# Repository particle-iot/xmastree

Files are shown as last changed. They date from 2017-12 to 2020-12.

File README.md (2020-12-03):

# PARTICLE CHRISTMAS TREE

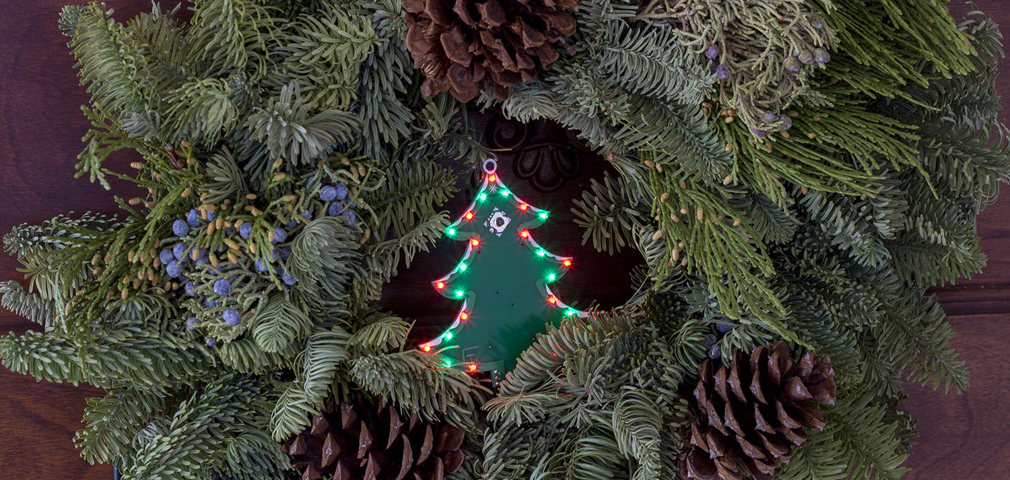
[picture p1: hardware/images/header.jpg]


It's a Happy Hardware Holiday for all! Meet the Particle Christmas Tree, a limited edition PCB packed full of cheer with customizable light patterns and holiday tunes. Use your tree with a Particle Photon or Electron to light up the LEDs and play music. Control your tree from the onboard joystick or from the Christmas Tree Web App.

Learn how to get started below. Happy Holidays from Team Particle!

## THINGS YOU'LL NEED
 - Christmas Tree
 - Micro USB cable
 - USB power supply (2A minimum rating)
 - Your Photon or Electron (new to Particle? Get started [here](https://docs.particle.io/guide/getting-started).)
 - Eggnog (optional)

## STEPS 

You can setup the tree in a matter of minutes.

1. Insert the Photon into the socket
1. Plug in the USB power supply
1. Flash [the Christmas tree firmware from the Web IDE][Firmware shared app] - no downloads required.
1. [Open the web interface][Web interface] and spread the cheer!

[Firmware shared app]: https://go.particle.io/shared_apps/5fc8c888e6f0b000092cf113
[Web interface]: https://particle-iot.github.io/xmastree

<p align="center">
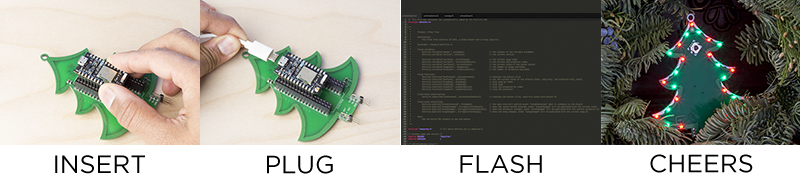
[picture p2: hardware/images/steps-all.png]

</p>

## GET TO KNOW YOUR TREE

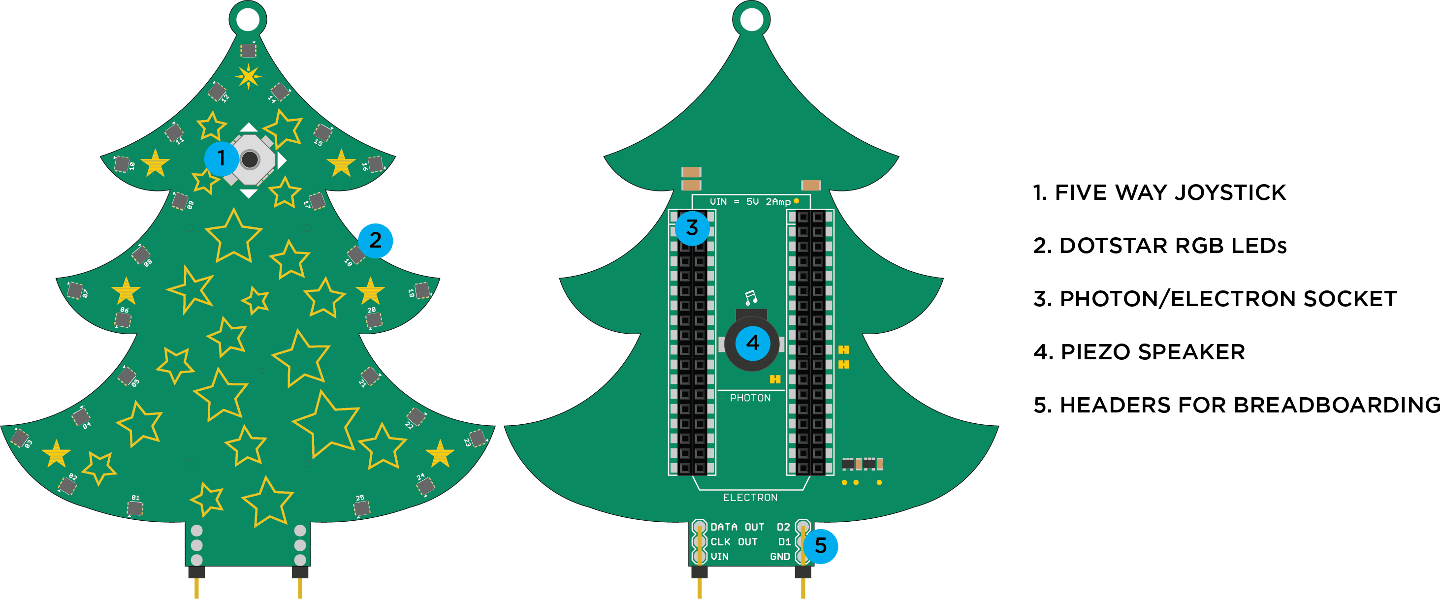
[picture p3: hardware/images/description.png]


### Joystick

The joystick is a 5 way button: up, down, left, right, and center (push in) then you can reprogram the usage any way you'd like. We have setup the button for you in the Christmas tree firmware to toggle light patterns and music.

|DIR | PIN |
|:---  |:--- |
|UP |D4| 
|DOWN  |A0|
|LEFT  |D5|
|RIGHT |D3|
|CENTER|D6|

### Dotstar RGB LEDs

The tree has 25 of the [APA102](http://www.led-color.com/upload/201604/APA102-2020%20SMD%20LED.pdf) 2020 RGB LEDs (also commonly known as dotstars) connected in a daisy chain. These LEDs are individually addressable using two pins, data and clock. These tiny stars are incredibly bright and fast. At full brightness, with all colors turned ON, each LED will consume about 60mA of current. So 25 of them will consume a max of 1.5Amp. This is why we recommend powering the tree with a **5VDC power supply that can source at least 2Amp.** Most modern USB phone chargers should be able to meet this demand.

### Photon/Electron Socket

The two dual-row headers allow you to use either the Particle Photon or the Electron. Please take care of the orientation and position of the device while plugging in.

### Piezo speaker

At the back of the tree you'll find a piezo speaker connected to pin D0. The firmware includes several 8-bit holiday tunes but you can also compose your own. This speaker can be a bit loud. If you'd like to reduce the volume, you can put a piece of tape on its opening.

### Headers for breadboarding

These pins breakout the power and control signal of the tree. You can mount the tree on a breadboard with the help of these pins. This will allow you to connect different hardware to your tree, daisy chain multiple trees, add more LEDs or even control it with other microcontrollers.

|PIN |DESCRIPTION|
|:---|:---|
|D1 | Connected to the D1 pin of the Particle device and acts as CLOCK IN to the LEDs.|
|D2 | Connected to the D2 pin of the Particle device and acts as DATA IN to the LEDs.|
|DATA OUT| DATA OUT pin of the LEDs.|
|CLK OUT | CLOCK OUT pin of the LEDs.|
|VIN | Input power to the tree and Particle device. This pin is connected to the VIN pin of the Particle device. 5VDC max .|
|GND | Connected to the ground.|

## SETTING UP THE TREE 

You can either use a Particle Photon or an Electron to control the tree. Since the dotstar RGB LEDs work at 5VDC, you'll need to make sure that the USB cable is plugged in at all times to power the tree, unless you have powered the tree via a separate power source via the VIN pin.

> **NOTE:** When controlled by an Electron, the tree will not work with just the LiPo battery plugged in. You'll need to connect the USB cable as well or other external 5V DC power source.

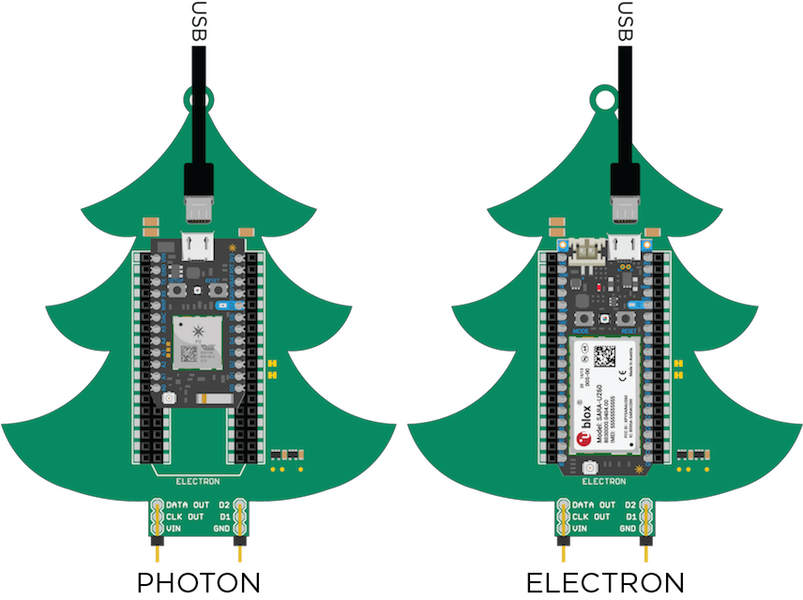
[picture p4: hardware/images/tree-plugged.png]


## WAYS TO SET UP THE TREE

### As an ornament

The easiest way to setup the tree is to hang it as an ornament while powering over USB. You can also rig up your own 5V power supply cable and plug it into the header.

### On a breadboard

You can use the bottom header to mount the tree on a breadboard and power/control it via your own choice of hardware or to daisy chain the tree to other trees or dotstar projects.

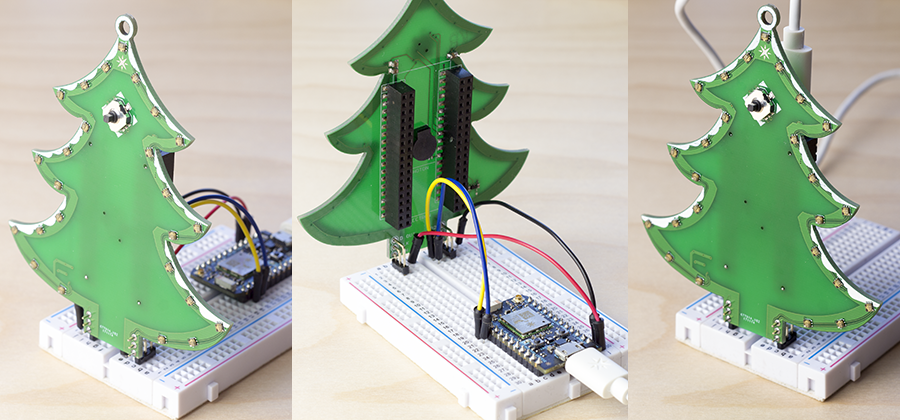
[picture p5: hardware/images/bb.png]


## USING THE WEB INTERFACE

<p align="center">
<a href="https://particle-iot.github.io/xmastree" target="_blank">
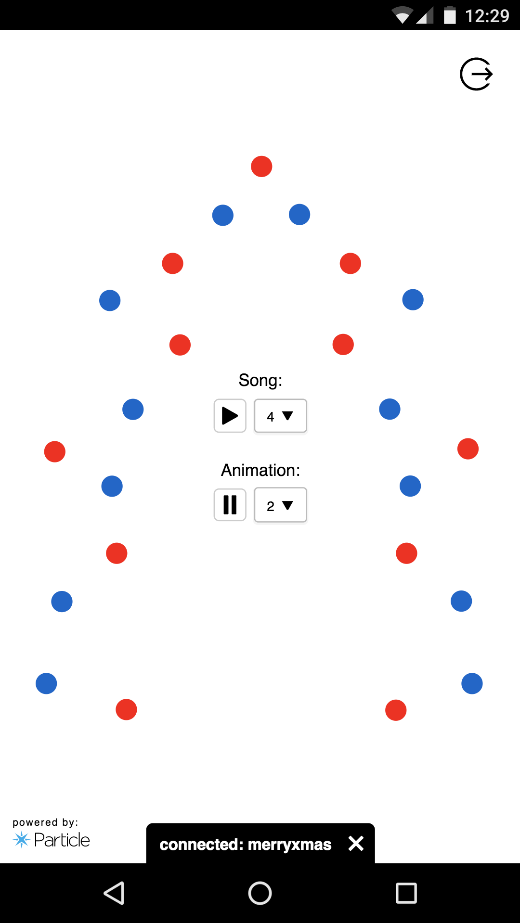
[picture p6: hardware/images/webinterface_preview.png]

</a></p>

There is [a hosted version of the web interface you can use to control your tree][Web interface]. Simply login with your Particle account, select your device and you'll be able to control the LEDs and music from a desktop or mobile browser.

## MODIFYING THE FIRMWARE

[][Firmware shared app]

Import the firmware to your Particle account in the Web IDE with the button above. You'll be
able to add new songs or tweak the functionality to your heart's
content.

Click [here](FIRMWARE.md) for more information about the Xmas Tree firmware.

## CONNECT

Having problems or have awesome suggestions? Connect with us on our [forum](https://community.particle.io/).

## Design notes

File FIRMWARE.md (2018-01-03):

# Particle Christmas Tree Firmware

## Introduction

The firmware of the Xmas Tree circuit board is based on Wiring to be run on Particle devices like the Photon and the Electron (or other compatible device like RedBear Duo) with cloud connectivity. For the details and installation, please refer to the Xmas Tree [user manual](/README.md). It controls the main components of the tree includes the 25 LEDs, the 5-way joystick and the piezo speaker. It detects the 5-way joystick buttons for user inputs to select LED animations and Xmas songs to play.

With the firmware, you will be able to learn how to use the Photon and the Electron connected to the cloud and demostrates how to:

* define cloud functions for controlling the tree over the Particle cloud
* generate tones using the piezo buzzer
* create beautiful animation effects using the LEDs
* control the tree state using the 5-way joystick

Feel free to hack, modify or inspire any new features in the firmware source code and remember to share with everyone for your great work. An example of new feature is to add an ultrasonic sensor to the tree for motion detection and then the tree starts to play a paricular song or LED animation.

## How It Works

The firmware keeps track of user inputs by monitoring the 5-way joystick button and performs the following tasks:

|BUTTON|TASKS|
|:---  |:--- |
|UP |Play Previous Animation| 
|DOWN  |Play Next Animation|
|LEFT  |Play Previous Song|
|RIGHT |Play Next Song|
|CENTER|Toggle Tree State|

The CENTER button controls the tree with four states by toggling the following sequence:

*	(S) --> Play Both Song and Animation --> Stop Both --> Play Animation Only --> Play Song Only --> (S) 

## Source Files

### xmastree.ino

The firmware starts from the [xmastree.ino](/src/firmware/xmastree.ino) and it calls the `setup()` function at once for setting up and initialize the hardware components:

* `ledsInit()`, LEDs by using the dotstar library
* `joystickPortInit()`, 5-way joystick button with interrupt enabled
* `buzzerPortInit()`, piezo speaker

It also exposes the tree cloud functions and variables, subscribes to the tree cloud events as well:

* `cloudInit()`

After that, it will create two threads (as workers) for processing the pre-defined songs and animations:

* `animationWorker`
* `songWorker`
  
Finally, it runs the `loop()` function repeatedly to keep track of buttons and cloud events.

It calls `processButtons()` for user inputs and by adding/subtracting the variables `currentState`, `currentSong` and `currentAnimation` so that the threads can handle how to play the songs and animations. Also, it calls `processCloud()` for any events coming from the cloud over the Internet and controlling the variables as well.

Note: You can set the brightness of the LEDs to higher but less than 80 is highly recommanded for safety (too hot) and your eyes (too bright).
 
* `#define LED_BRIGHTNESS      30` 

### xmastree.h

The [xmastree.h](/src/firmware/xmastree.h) header file defines the hardware pins of the components such as the piezo speaking and the 5-way joystick. It also defines some macros for using in the source code. Normally, you do not need to modify this file.  

### songs.h

The [songs.h](/src/firmware/songs.h) file contains some pre-defined Xmas songs to be gernerated by the piezo speaker. You can modify it by adding your favorite songs there.

### animations.h

The [animations.h](/src/firmware/animations.h) file contains some pre-defined LED animations to be gernerated by the 25 LEDs. You can modify it by adding your own LED animations there.

### Cloud Variables/Functions/Events

The cloud items are exposed for the [Web App](https://particle-iot.github.io/xmastree) to control the tree over the Internet so that you can control the tree remotely.

#### Variables

|NAME |DESCRIPTION |
|:--- |:--- |
|whoami |Variable `projName`, the current project name `xmastree` will be sent out by default|
|version  |Variable `version`, the current firmware version |
|currSong |Variable `currentSong`, the current song index |
|currAnim |Variable `currentAnimation`, the current LED animation index |
|currState|Variable `currentState`, the current state of the tree |
|songCount|Variable `songCount`, the number of songs available |
|animCount|Variable `animationCount`, the number of animations available |

#### Functions
 
|NAME |DESCRIPTION |
|:--- |:--- |
|setState |`setState()`, set the current state of the tree state (none, song only, led animation only, both)|
|playSong |`playSong(String index)`, play song by index|
|stopSong |`stopSong()`, stop song|
|playAnim |`playAnimation(String index)`, play LED animation by index|
|stopAnim |`stopAnimation()`, stop LED animation|

#### Events (Publishing)

|NAME |DESCRIPTION |
|:--- |:--- |
|xtreeConnected |Variable `ProjName`, the xmas tree will publish event "xtreeConnected" with the variable once it connects to the clould |
|stateChanged |Variable `currentState`, when the center button pressed, event "stateChanged" will be published with the current state|
|animChanged |Variable `currentAnimation`, when the animation changed, event "animChanged" will be published with the current animation ID|
|songChanged |Variable `currentSong`, when the song changed, event "songChanged" will be published with the current song ID|

You can add your own events to the firmware and use the [console](https://console.particle.io/events) to monitor the cloud events for testing.

## Credits

* [midiToArduino](https://www.extramaster.net/tools/midiToArduino/)

## References

* [Main Page](https://github.com/particle-iot/xmastree)
* [User Manual](/README.md)
* [Web App](https://particle-iot.github.io/xmastree)

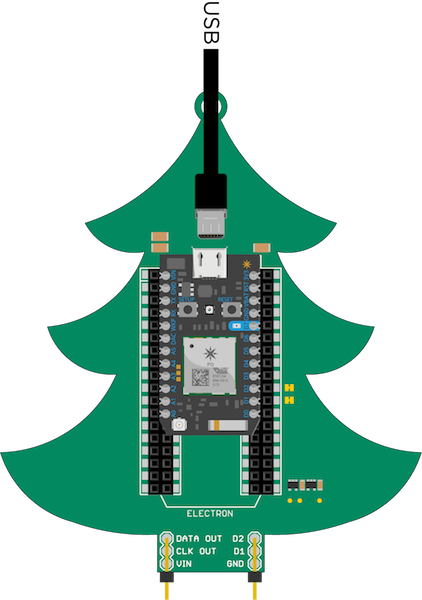
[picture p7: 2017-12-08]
hardware/images/tree-photon.png

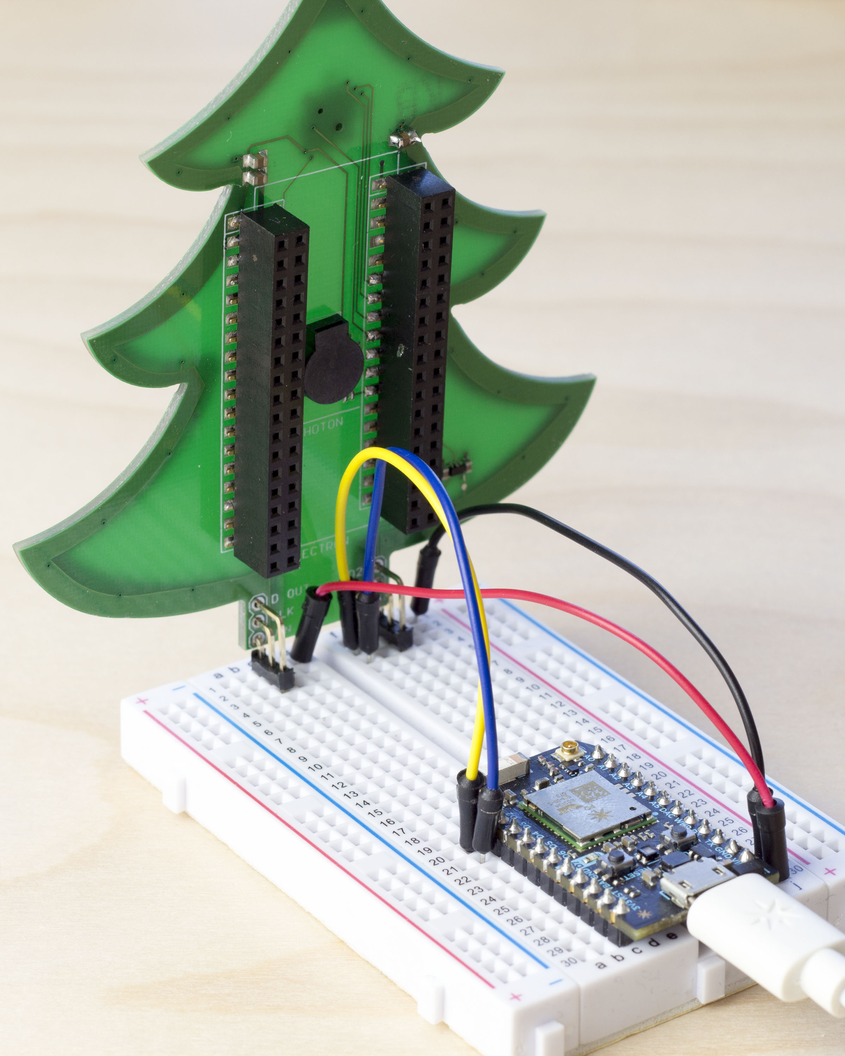
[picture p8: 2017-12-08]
hardware/images/bb03.jpg

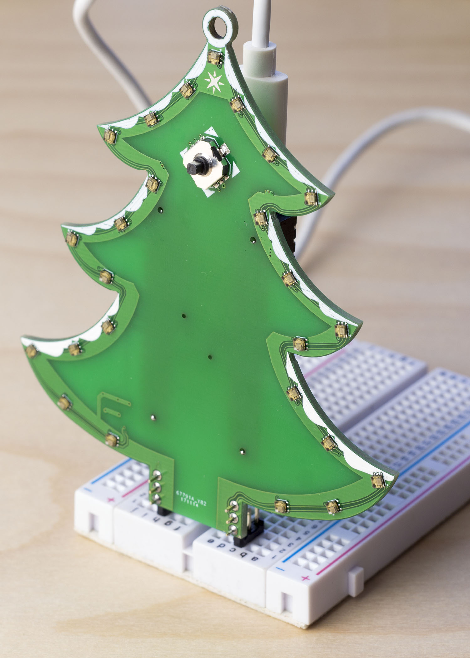
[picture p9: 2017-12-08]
hardware/images/bb01.jpg

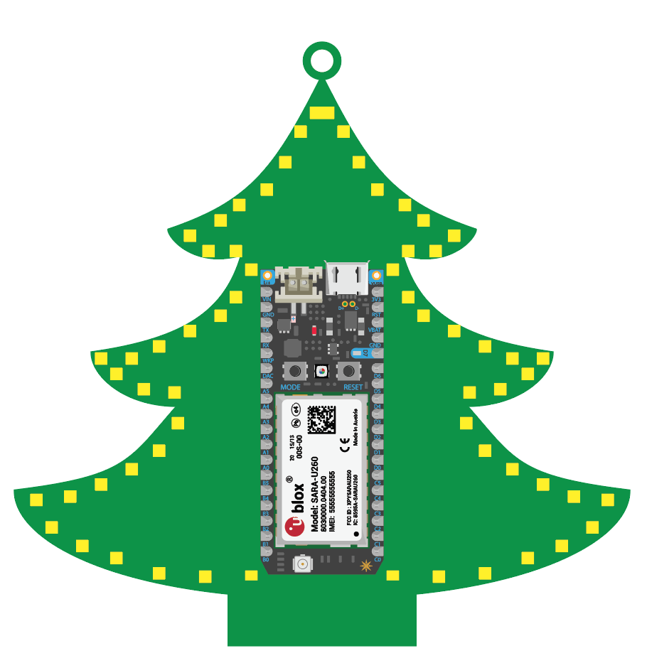
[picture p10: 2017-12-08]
hardware/images/shape-mockup.jpg

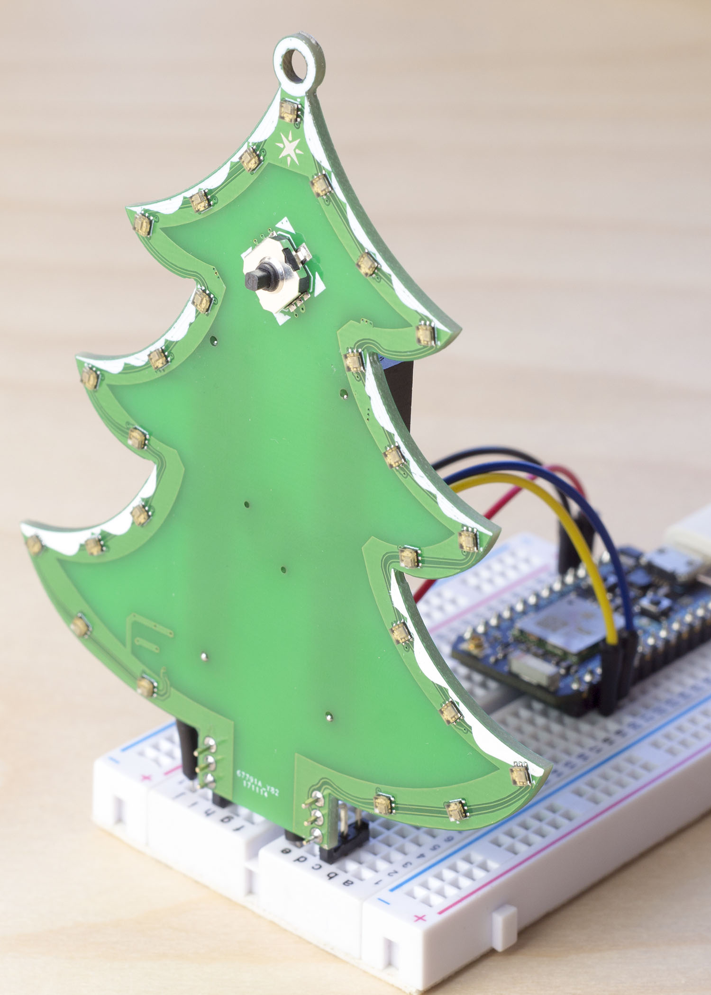
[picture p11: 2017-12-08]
hardware/images/bb02.jpg

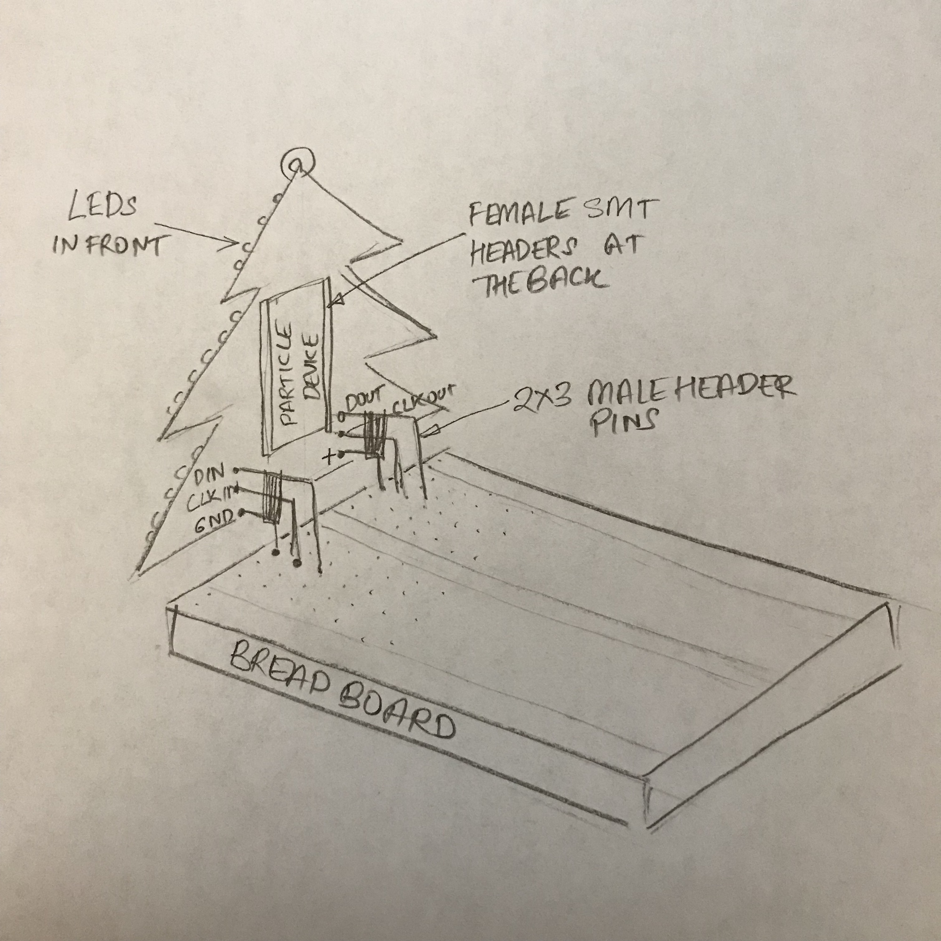
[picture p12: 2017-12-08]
hardware/images/header-location.jpg

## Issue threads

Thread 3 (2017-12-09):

Set RGB ordering

beriberikix, 2017-12-09:
In order to get the correct color when calling `setPixelColor()`, I had to change the initialization to:
`Adafruit_DotStar leds = Adafruit_DotStar(TOTAL_LED, PIN_LED_DATA, PIN_LED_CLOCK, DOTSTAR_BGR);`

@Cheong2K are you able to confirm if that's needed?

Cheong2K, 2017-12-16:
Thanks @beriberikix and @monkbroc for fixing this, nice!!

Closed 2017-12-15.

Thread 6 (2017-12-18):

Twinkle

Mohoganogan, 2017-12-18:
How about one that is all green and then a single random led twinkles white then goes back to green to provide an old school simple look.

beriberikix, 2017-12-18:
Great idea @Mohoganogan! We can see if someone has a extra time but pull requests are always welcome!

Mohoganogan, 2017-12-30:
I ended up using this code for my tree:
[https://github.com/WTFox/xmas-tree](https://github.com/WTFox/xmas-tree)

Modified to use only one of the patterns.

`// This #include statement was automatically added by the Particle IDE.
// https://github.com/WTFox/xmas-tree
#include <FastLED.h>

#include "FastLED/FastLED.h"
FASTLED_USING_NAMESPACE;

#if FASTLED_VERSION < 3001000
#error "Requires FastLED 3.1 or later; check github for latest code."
#endif

#define DATA_PIN D2
#define CLOCK_PIN D1
#define LED_TYPE WS2811
#define COLOR_ORDER GRB
#define NUM_LEDS 25
CRGB leds[NUM_LEDS];

#define BRIGHTNESS 5
#define FRAMES_PER_SECOND 12
#define MAX_ARGS 64

#define ARRAY_SIZE(A) (sizeof(A) / sizeof((A)[0]))

int lightsOn(String input);
int lightsOff(String input);
int toggleLights(String args);
int setBright(String brightness);
int twitterMention(String args);
void addGlitter(NSFastLED::fract8 chanceOfGlitter);

// list of patterns to cycle through.  each is defined as a separate function
// below.
typedef void (*SimplePatternList[])();
SimplePatternList gPatterns = {confetti};
//SimplePatternList gPatterns = {rainbow, rainbowWithGlitter, confetti, sinelon, juggle, bpm};

uint8_t gCurrentPatternNumber = 0;  // Index number of which pattern is current
uint8_t gHue = 0;  // rotating "base color" used by many of the patterns

void setup() {
  // Publishing particle functions and vars.
  FastLED.addLeds<APA102, DATA_PIN, CLOCK_PIN>(leds, NUM_LEDS);
  Particle.function("lightsOn", lightsOn);
  Particle.function("lightsOff", lightsOff);
  Particle.function("toggleLights", toggleLights);
  Particle.function("brightness", setBright);
  Particle.function("tweet", tweet);
  Particle.function("twitMention", twitterMention);
  delay(3000);  // 3 second delay for recovery

//  FastLED.addLeds<LED_TYPE, DATA_PIN, COLOR_ORDER>(leds, NUM_LEDS).setCorrection(TypicalLEDStrip);

  // set master brightness control
  FastLED.setBrightness(BRIGHTNESS);
}

bool mentioned = false;
bool lightState = true;
bool currentState = true;
int lightBrightness = 100;

String onMessages[] = {"Lighting it up for Christmas!",
                       "Let's get LIT!",
                       "HO HO HO!, It's Christmas Time!",
                       "Christmas Tree, OH Christmas ME!",
                       "My lights are brightly shining!"};

String offMessages[] = {"No more xmas.. FOR NOW!?",
                        "I'm going to sleep. ZZzz...ZZzzz..",
                        "O-Holy-Night!",
                        "Going away. I'll be home for Christmas"};

void loop() {
  // main loop
  if (currentState != lightState) {
    lightState = currentState;
  }

  if (lightState == true) {
    // Call the current pattern function once, updating the 'leds' array
    gPatterns[gCurrentPatternNumber]();

    // send the 'leds' array out to the actual LED strip
    FastLED.show();
    // insert a delay to keep the framerate modest
    FastLED.delay(1000 / FRAMES_PER_SECOND);

    // do some periodic updates
    // slowly cycle the "base color" through the rainbow
    EVERY_N_MILLISECONDS(20) {
        gHue++;
        if (mentioned) {
            // Blink the tree lights 5 times if mentioned on twitter
            for (int i=0; i<5; i++) {
                FastLED.clear();
                FastLED.show();
                delay(250);
                rainbow();
                FastLED.show();
                delay(250);
            }
            mentioned = false;
        }
    }

    // change patterns periodically
    EVERY_N_SECONDS(10) {
        nextPattern();
    }
  }
}

// Particle functions.
// Per the docs, hese functions HAVE to return an int
// and accept a String as a parameter.
int tweet(String msg) {
    Particle.publish("sendTweet", msg, 60, PRIVATE);
    return 0;
}

int setBright(String brightness) {
  lightBrightness = brightness.toInt();
  FastLED.setBrightness(lightBrightness);
  return 0;
}

int toggleLights(String args) {
  int index = args.toInt();
  int value;
  char szArgs[MAX_ARGS];

  args.toCharArray(szArgs, MAX_ARGS);

  sscanf(szArgs, "%d=%d", &index, &value);

  if (value == 1) {
    lightsOn("");
  } else if (value == 0) {
    lightsOff("");
  }
  return 1;
}

int lightsOn(String input) {
  currentState = true;
  FastLED.show();

  int size = sizeof(onMessages) / sizeof(onMessages[0]);
  String msg = onMessages[random(0, size)];
  tweet(msg);

  return 0;
}

int lightsOff(String input) {
  currentState = false;
  FastLED.clear();
  FastLED.show();

  int size = sizeof(offMessages) / sizeof(offMessages[0]);
  String msg = offMessages[random(0, size)];
  tweet(msg);

  return 0;
}

int twitterMention(String args) {
    mentioned = true;
    String message = args + ", Thanks for the mention!";
    tweet(message);
    return 0;
}

// Light and pattern functions
void nextPattern() {
  // add one to the current pattern number, and wrap around at the end
  gCurrentPatternNumber = (gCurrentPatternNumber + 1) % ARRAY_SIZE(gPatterns);
}

void rainbow() {
  // FastLED's built-in rainbow generator
  fill_rainbow(leds, NUM_LEDS, gHue, 7);
}

void addGlitter(NSFastLED::fract8 chanceOfGlitter) {
  if (random8() < chanceOfGlitter) {
    leds[random16(NUM_LEDS)] += CRGB::White;
  }
}

void rainbowWithGlitter() {
  // built-in FastLED rainbow, plus some random sparkly glitter
  rainbow();
  addGlitter(80);
}

void confetti() {
  // random colored speckles that blink in and fade smoothly
  fadeToBlackBy(leds, NUM_LEDS, 10);
  int pos = random16(NUM_LEDS);
  leds[pos] += CHSV(gHue + random8(64), 200, 255);
}

void sinelon() {
  // a colored dot sweeping back and forth, with fading trails
  fadeToBlackBy(leds, NUM_LEDS, 20);
  int pos = beatsin16(13, 0, NUM_LEDS);
  leds[pos] += CHSV(gHue, 255, 192);
}

void bpm() {
  // colored stripes pulsing at a defined Beats-Per-Minute (BPM)
  uint8_t BeatsPerMinute = 62;
  CRGBPalette16 palette = PartyColors_p;
  uint8_t beat = beatsin8(BeatsPerMinute, 64, 255);
  for (int i = 0; i < NUM_LEDS; i++) {  // 9948
    leds[i] = ColorFromPalette(palette, gHue + (i * 2), beat - gHue + (i * 10));
  }
}

void juggle() {
  // eight colored dots, weaving in and out of sync with each other
  fadeToBlackBy(leds, NUM_LEDS, 20);
  byte dothue = 0;
  for (int i = 0; i < 8; i++) {
    leds[beatsin16(i + 7, 0, NUM_LEDS)] |= CHSV(dothue, 200, 255);
    dothue += 32;
  }
}

`

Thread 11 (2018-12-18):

Mesh devices

causalloop, 2018-12-18:
Got one of the xenon to photon pin adapters and hooked it up to the tree - had to use [this version of dotstar](https://github.com/BlackLamb/Particle-DotStar/tree/aafce0b10201e2292df29d408ad81048fe580be9/src)  which works great, but the web ui doesn't support anything other than the core/photon/electron and fails on detection.  The button works though.. :-P

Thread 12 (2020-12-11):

Crashes with DeviceOS 2.0.0 due to missing return

ScruffR, 2020-12-11:
`int playLED()` fails to return a value and starting with 2.0.0 this causes a SOS panic crash.

Adding `return strtol(color, NULL, 0);` at the bottom of this function should do the trick

https://github.com/particle-iot/xmastree/blob/master/src/firmware/xmastree.ino#L101

wesleycombs, 2021-12-10:
Thanks @ScruffR - that did the trick.

nothans, 2024-11-16:
Yes, this worked for me too.

I ended up with just returning a "1" since playLED was defined as an int.

```
int playLED(String color)
{
    for (int i = 0; i < TOTAL_LED; i++)
        leds.setPixelColor(i, strtol(color, NULL, 0));
    leds.show();
    return 1;
}
```

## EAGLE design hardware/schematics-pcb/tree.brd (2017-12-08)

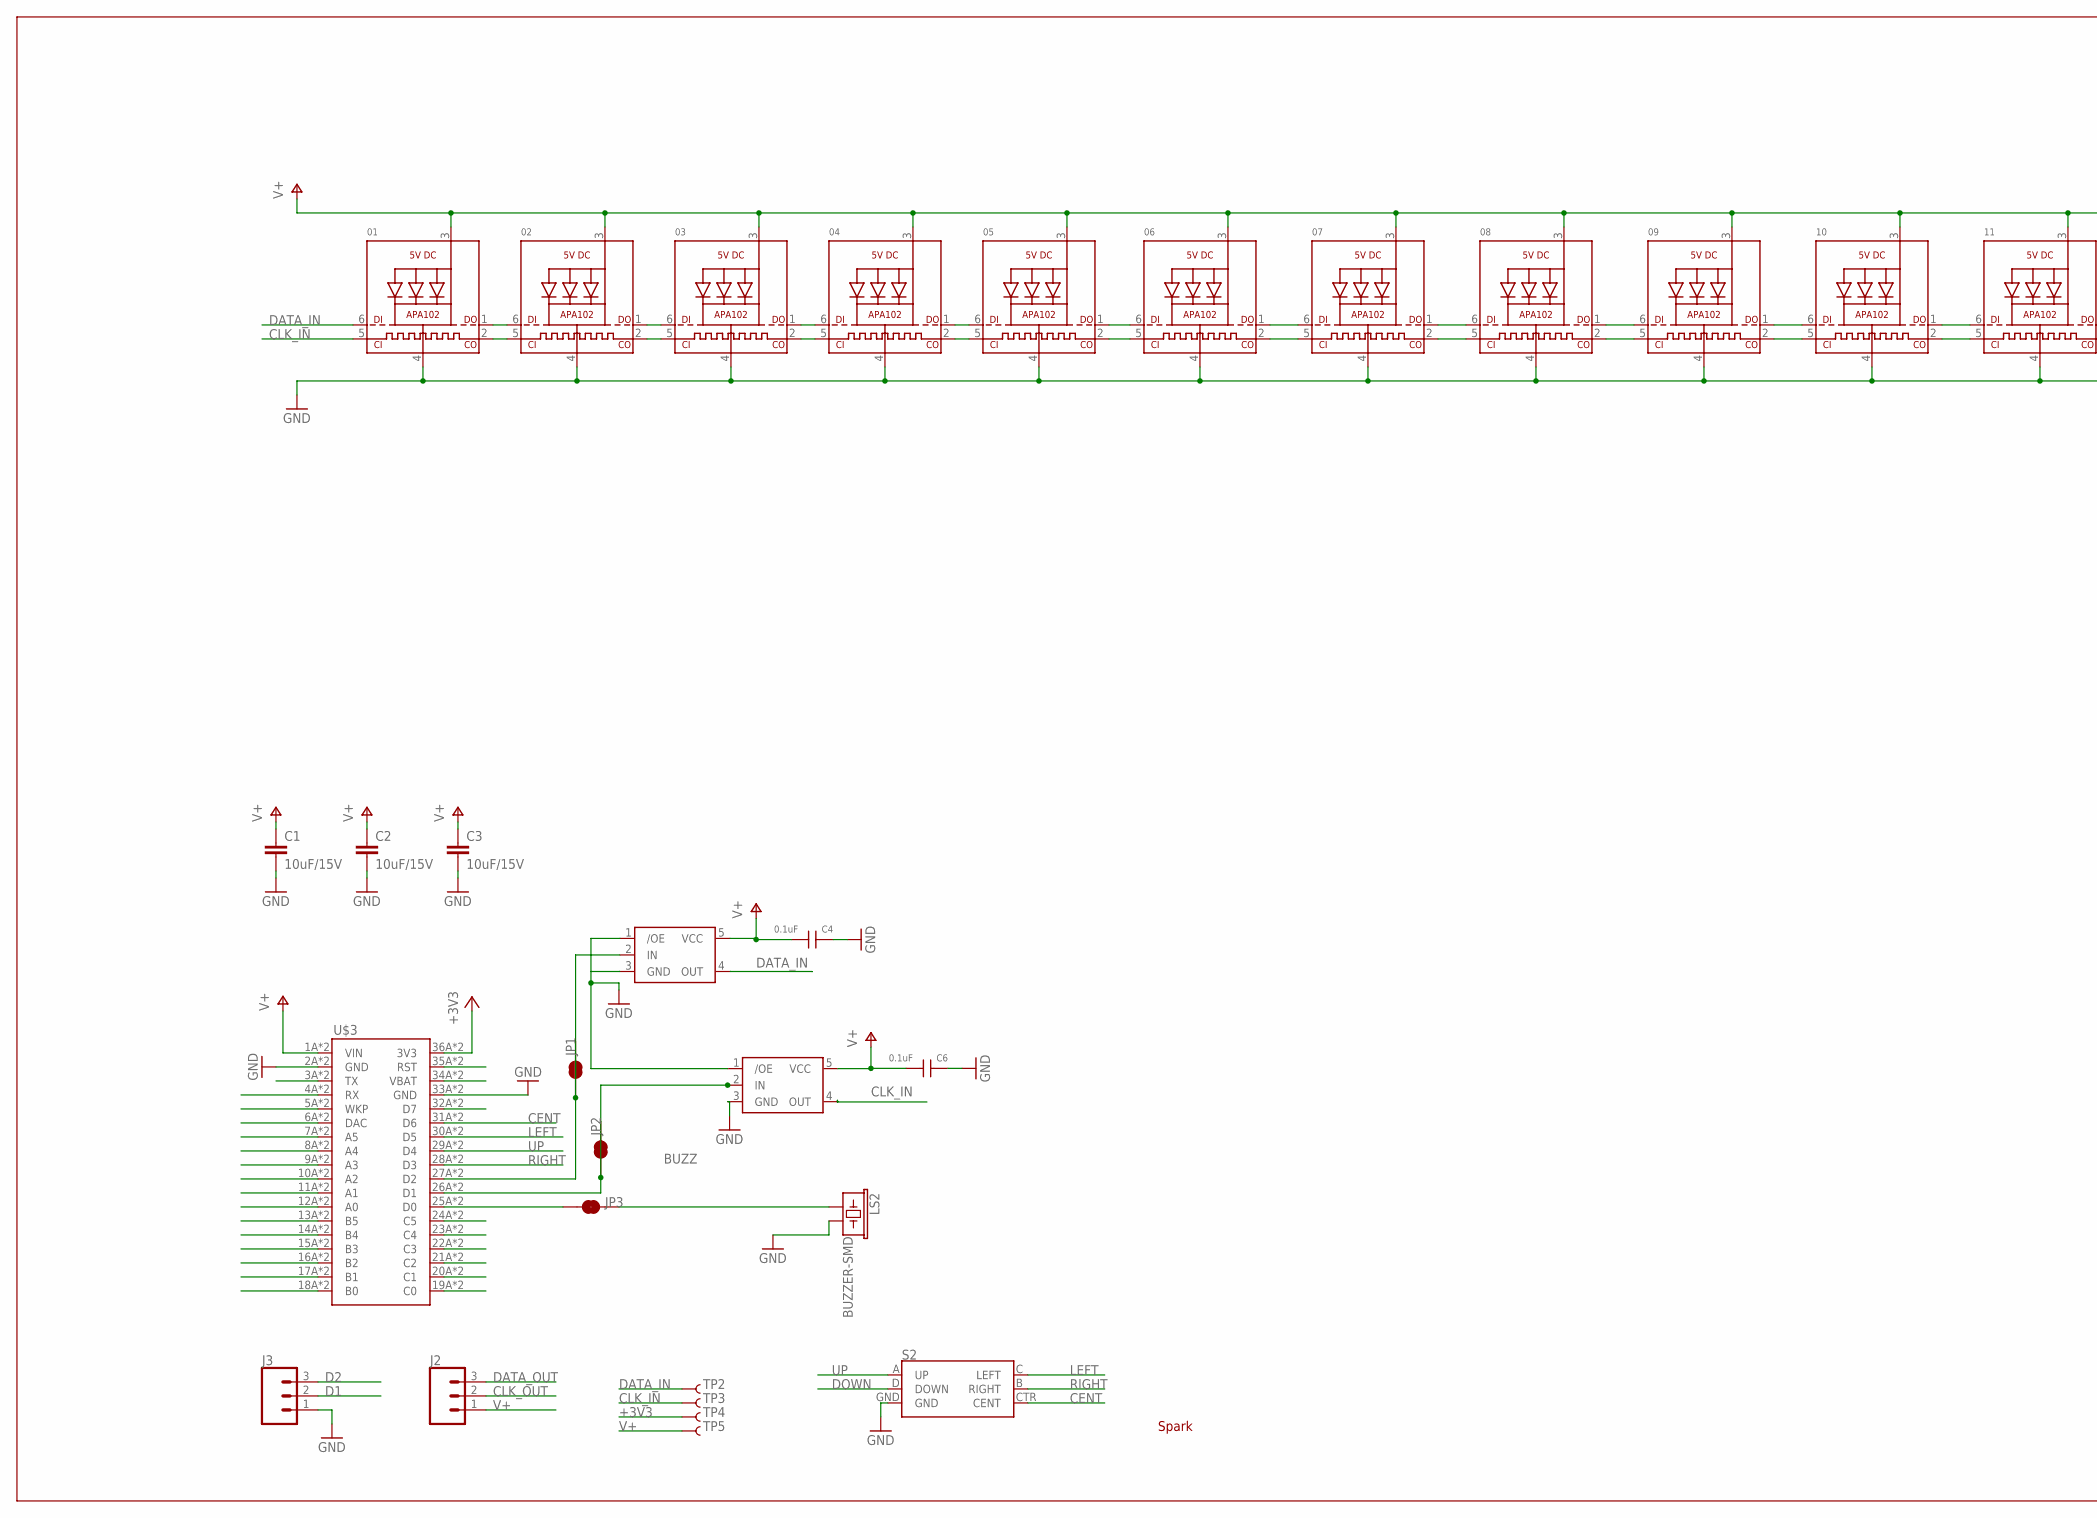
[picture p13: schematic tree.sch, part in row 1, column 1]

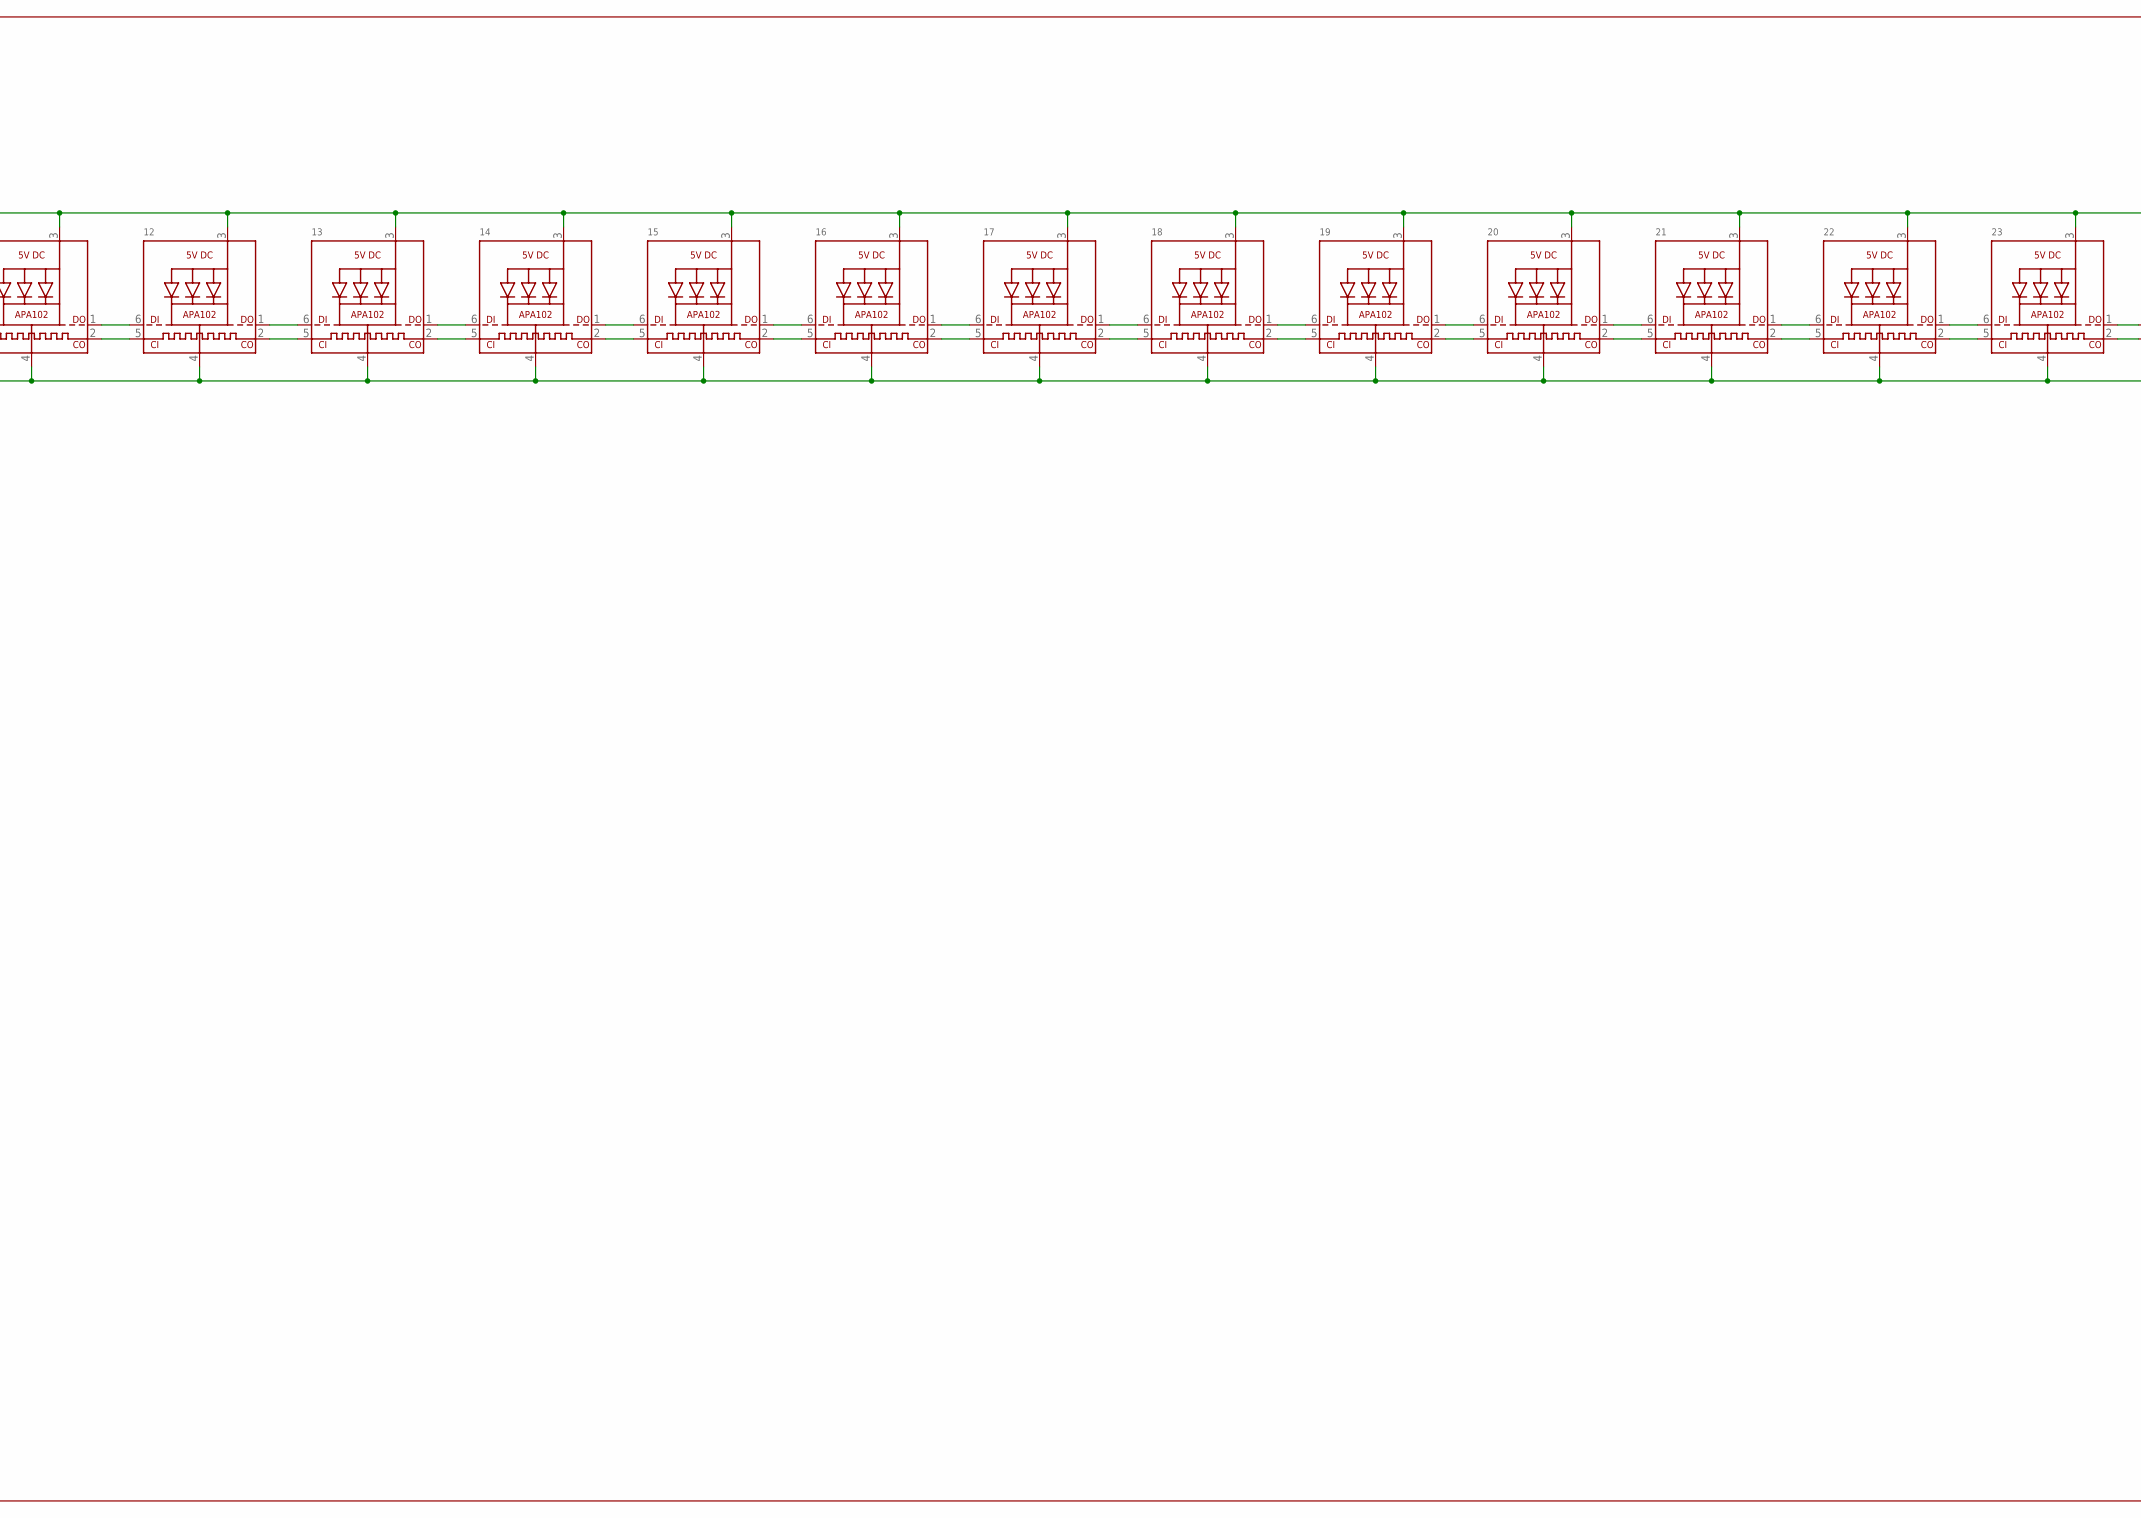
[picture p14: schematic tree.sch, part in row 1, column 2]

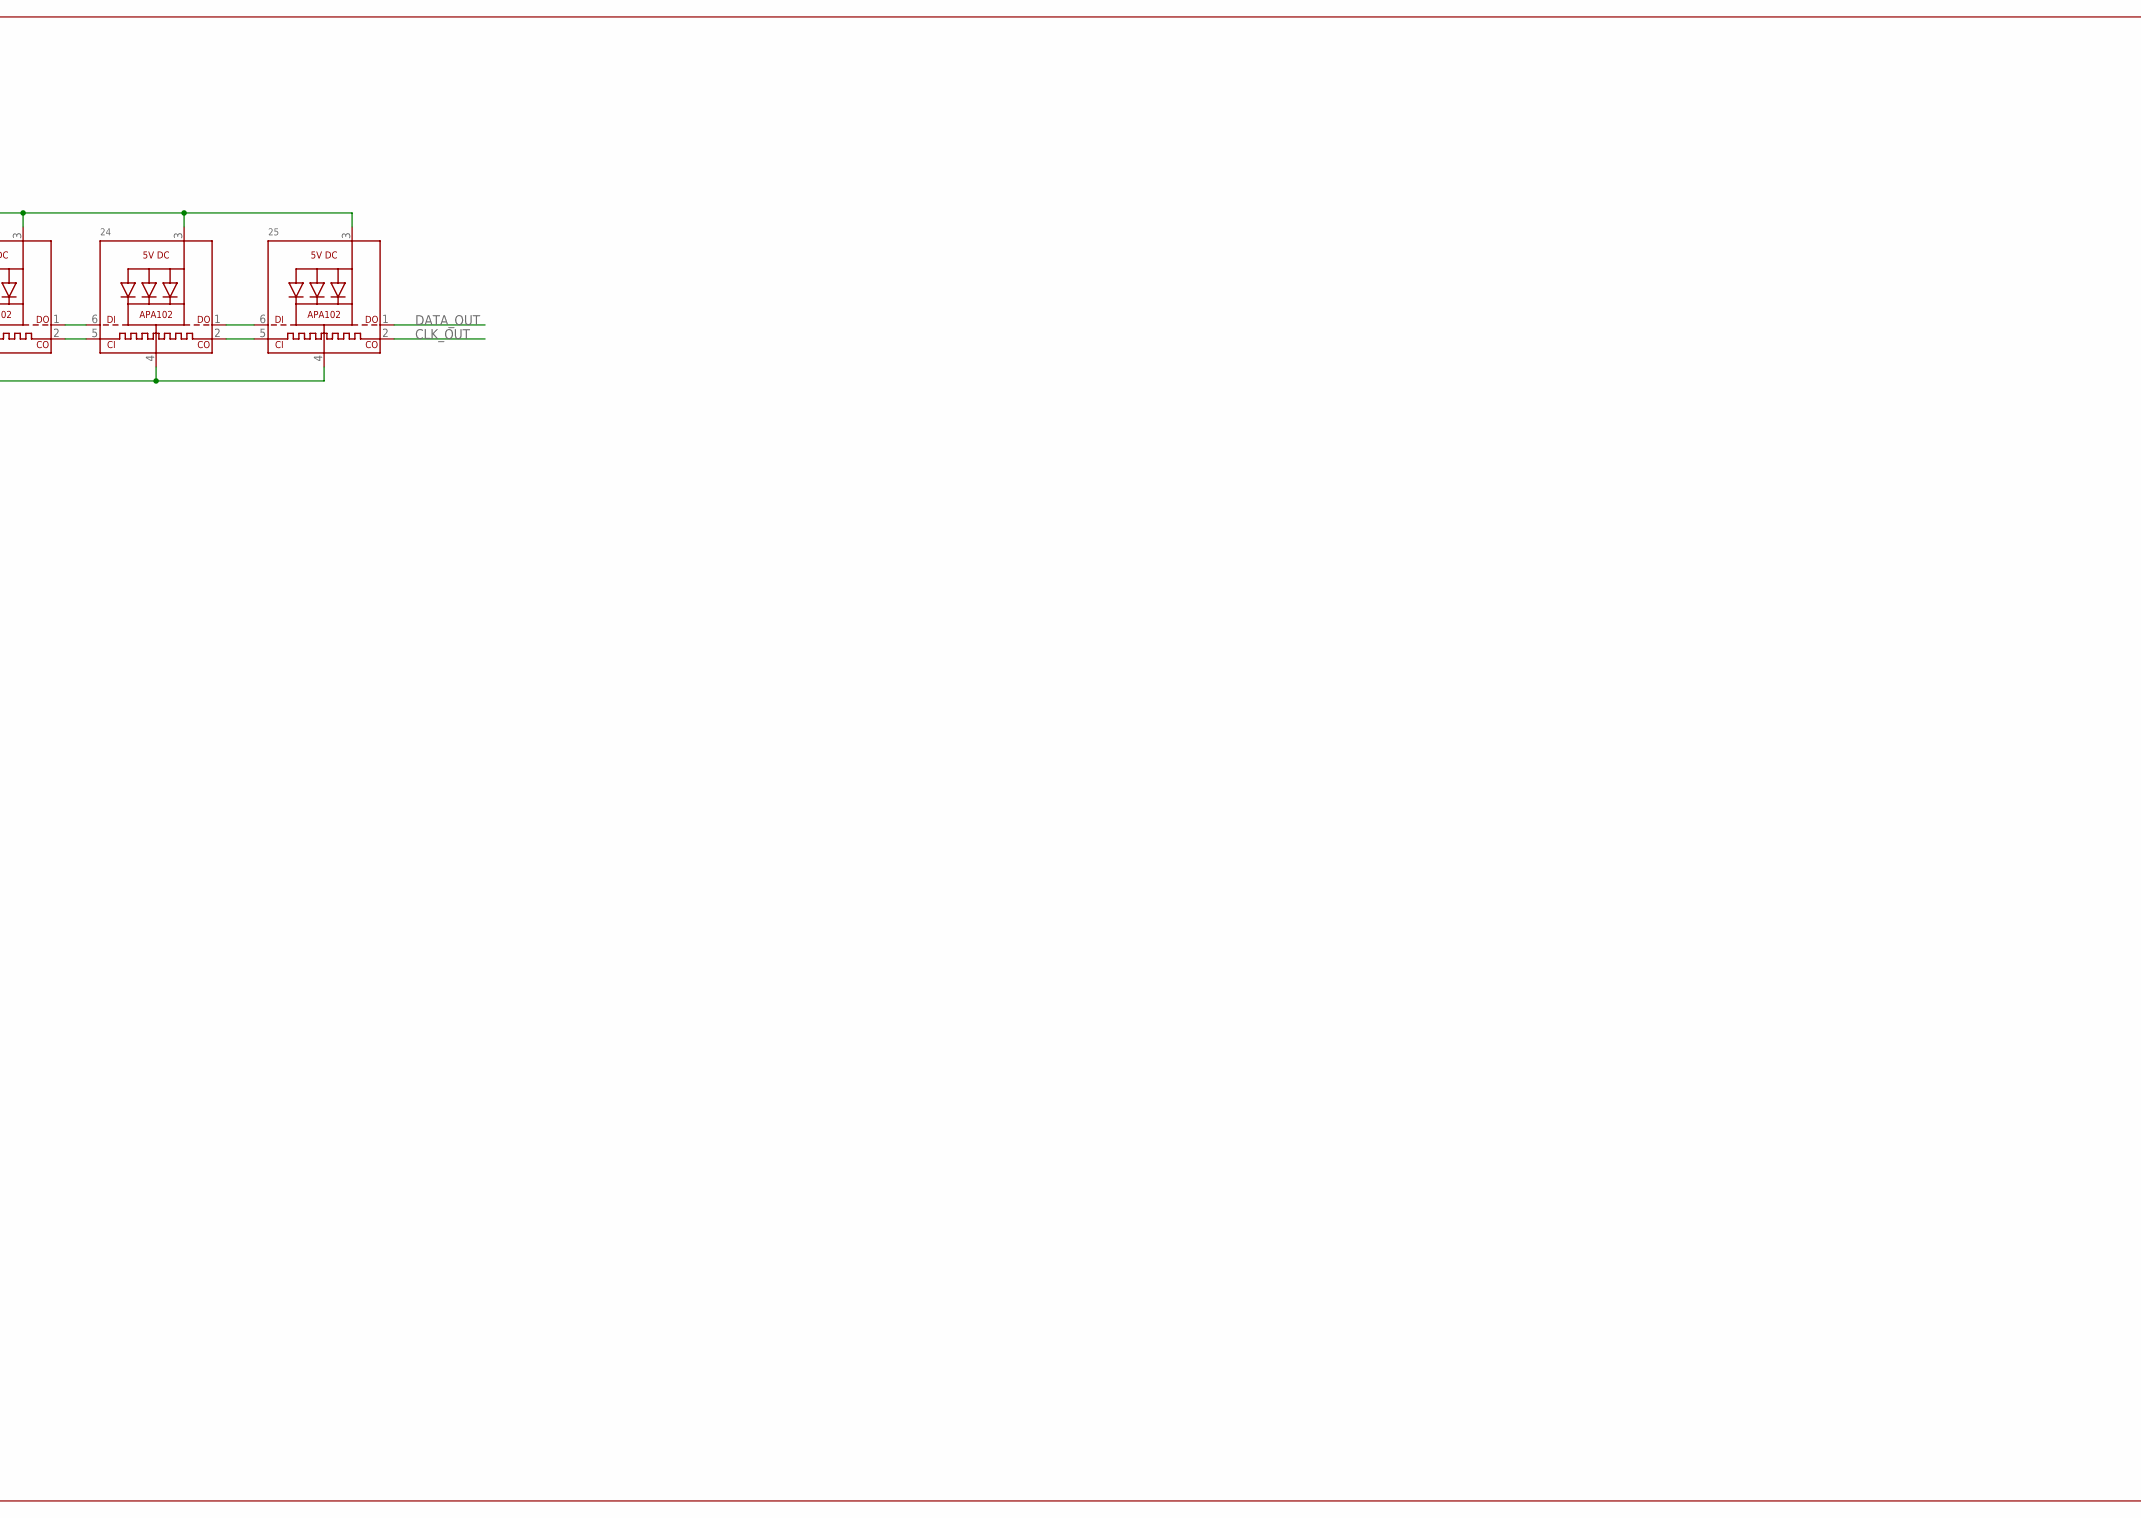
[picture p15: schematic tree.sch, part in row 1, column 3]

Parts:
01, 02, 03, 04, 05, 06, 07, 08, 09, 10, 11, 12, 13, 14, 15, 16, 17, 18, 19, 20, 21, 22, 23, 24, 25: APA1022020; APA102_2020
C1, C2, C3: 10uF/15V; C0805K
C4, C6: 0.1uF; C-0603A
J2, J3: CONN_03; 1X03
JP1, JP2, JP3: JUMPER-SMT_2_NC_TRACE_NO-SILK; SMT-JUMPER_2_NC_TRACE_NO-SILK
LS2: BUZZER-SMD; BUZZER-CCV
S2: JOYSTICK_MINI
TP2, TP3, TP4, TP5: TEST-POINT3; PAD.03X.03
U1, U2: NL17SZ125; SOT-353
U$1: SPARK_LOGO; SPARK_LOGO_TSTOP
U$3: ELECTRON_SMT

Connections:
+3V3: TP4.P$1, U$3.36A (3V3), U$3.36B (3V3)
BUZZ: JP3.1, U$3.25A (D0), U$3.25B (D0)
CENT: S2.CTR (CENT), U$3.31A (D6), U$3.31B (D6)
CLK_IN: 01.5 (CKI), TP3.P$1, U2.4 (OUT)
CLK_OUT: 25.2 (CKO), J2.2
D1: J3.2, JP2.1, JP2.2, U2.2 (IN), U$3.26A (D1), U$3.26B (D1)
D2: J3.3, JP1.1, JP1.2, U1.2 (IN), U$3.27A (D2), U$3.27B (D2)
DATA_IN: 01.6 (DI), TP2.P$1, U1.4 (OUT)
DATA_OUT: 25.1 (DO), J2.3
DOWN: S2.D (DOWN), U$3.12A (A0), U$3.12B (A0)
GND: 01.4 (GND), 02.4 (GND), 03.4 (GND), 04.4 (GND), 05.4 (GND), 06.4 (GND), 07.4 (GND), 08.4 (GND), 09.4 (GND), 10.4 (GND), 11.4 (GND), 12.4 (GND), 13.4 (GND), 14.4 (GND), 15.4 (GND), 16.4 (GND), 17.4 (GND), 18.4 (GND), 19.4 (GND), 20.4 (GND), 21.4 (GND), 22.4 (GND), 23.4 (GND), 24.4 (GND), 25.4 (GND), C1.2, C2.2, C3.2, C4.2, C6.2, J3.1, LS2.- (2), S2.GND, U1.1 (/OE), U1.3 (GND), U2.1 (/OE), U2.3 (GND), U$3.2A (GND), U$3.2B (GND), U$3.33A (GND), U$3.33B (GND)
LEFT: S2.C (LEFT), U$3.30A (D5), U$3.30B (D5)
unnamed: U$3.24A (C5), U$3.24B (C5)
unnamed: JP3.2, LS2.+ (1)
unnamed: 01.1 (DO), 02.6 (DI)
unnamed: 01.2 (CKO), 02.5 (CKI)
unnamed: 02.1 (DO), 03.6 (DI)
unnamed: 02.2 (CKO), 03.5 (CKI)
unnamed: 03.1 (DO), 04.6 (DI)
unnamed: 03.2 (CKO), 04.5 (CKI)
unnamed: 04.1 (DO), 05.6 (DI)
unnamed: 04.2 (CKO), 05.5 (CKI)
unnamed: 05.1 (DO), 06.6 (DI)
unnamed: 05.2 (CKO), 06.5 (CKI)
unnamed: 06.1 (DO), 07.6 (DI)
unnamed: 06.2 (CKO), 07.5 (CKI)
unnamed: 07.1 (DO), 08.6 (DI)
unnamed: 07.2 (CKO), 08.5 (CKI)
unnamed: 08.1 (DO), 09.6 (DI)
unnamed: 08.2 (CKO), 09.5 (CKI)
unnamed: 09.1 (DO), 10.6 (DI)
unnamed: 09.2 (CKO), 10.5 (CKI)
unnamed: 10.1 (DO), 11.6 (DI)
unnamed: 10.2 (CKO), 11.5 (CKI)
unnamed: 11.1 (DO), 12.6 (DI)
unnamed: 11.2 (CKO), 12.5 (CKI)
unnamed: 12.2 (CKO), 13.5 (CKI)
unnamed: 12.1 (DO), 13.6 (DI)
unnamed: 13.1 (DO), 14.6 (DI)
unnamed: 13.2 (CKO), 14.5 (CKI)
unnamed: 14.1 (DO), 15.6 (DI)
unnamed: 14.2 (CKO), 15.5 (CKI)
unnamed: 15.1 (DO), 16.6 (DI)
unnamed: 15.2 (CKO), 16.5 (CKI)
unnamed: 16.1 (DO), 17.6 (DI)
unnamed: 16.2 (CKO), 17.5 (CKI)
unnamed: 17.1 (DO), 18.6 (DI)
unnamed: 17.2 (CKO), 18.5 (CKI)
unnamed: 18.1 (DO), 19.6 (DI)
unnamed: 18.2 (CKO), 19.5 (CKI)
unnamed: 19.1 (DO), 20.6 (DI)
unnamed: 19.2 (CKO), 20.5 (CKI)
unnamed: 20.1 (DO), 21.6 (DI)
unnamed: 20.2 (CKO), 21.5 (CKI)
unnamed: 21.1 (DO), 22.6 (DI)
unnamed: 21.2 (CKO), 22.5 (CKI)
unnamed: 22.1 (DO), 23.6 (DI)
unnamed: 22.2 (CKO), 23.5 (CKI)
unnamed: 23.1 (DO), 24.6 (DI)
unnamed: 23.2 (CKO), 24.5 (CKI)
unnamed: 24.1 (DO), 25.6 (DI)
unnamed: 24.2 (CKO), 25.5 (CKI)
unnamed: U$3.19A (C0), U$3.19B (C0)
unnamed: U$3.32A (D7), U$3.32B (D7)
unnamed: U$3.35A (RST), U$3.35B (RST)
unnamed: U$3.34A (VBAT), U$3.34B (VBAT)
unnamed: U$3.23A (C4), U$3.23B (C4)
unnamed: U$3.22A (C3), U$3.22B (C3)
unnamed: U$3.21A (C2), U$3.21B (C2)
unnamed: U$3.20A (C1), U$3.20B (C1)
unnamed: U$3.18A (B0), U$3.18B (B0)
unnamed: U$3.17A (B1), U$3.17B (B1)
unnamed: U$3.16A (B2), U$3.16B (B2)
unnamed: U$3.15A (B3), U$3.15B (B3)
unnamed: U$3.14A (B4), U$3.14B (B4)
unnamed: U$3.13A (B5), U$3.13B (B5)
unnamed: U$3.11A (A1), U$3.11B (A1)
unnamed: U$3.10A (A2), U$3.10B (A2)
unnamed: U$3.9A (A3), U$3.9B (A3)
unnamed: U$3.8A (A4), U$3.8B (A4)
unnamed: U$3.7A (A5), U$3.7B (A5)
unnamed: U$3.6A (DAC), U$3.6B (DAC)
unnamed: U$3.5A (WKP), U$3.5B (WKP)
unnamed: U$3.4A (RX), U$3.4B (RX)
unnamed: U$3.3A (TX), U$3.3B (TX)
RIGHT: S2.B (RIGHT), U$3.28A (D3), U$3.28B (D3)
UP: S2.A (UP), U$3.29A (D4), U$3.29B (D4)
V+: 01.3 (VDD), 02.3 (VDD), 03.3 (VDD), 04.3 (VDD), 05.3 (VDD), 06.3 (VDD), 07.3 (VDD), 08.3 (VDD), 09.3 (VDD), 10.3 (VDD), 11.3 (VDD), 12.3 (VDD), 13.3 (VDD), 14.3 (VDD), 15.3 (VDD), 16.3 (VDD), 17.3 (VDD), 18.3 (VDD), 19.3 (VDD), 20.3 (VDD), 21.3 (VDD), 22.3 (VDD), 23.3 (VDD), 24.3 (VDD), 25.3 (VDD), C1.1, C2.1, C3.1, C4.1, C6.1, J2.1, TP5.P$1, U1.5 (VCC), U2.5 (VCC), U$3.1A (VIN), U$3.1B (VIN)

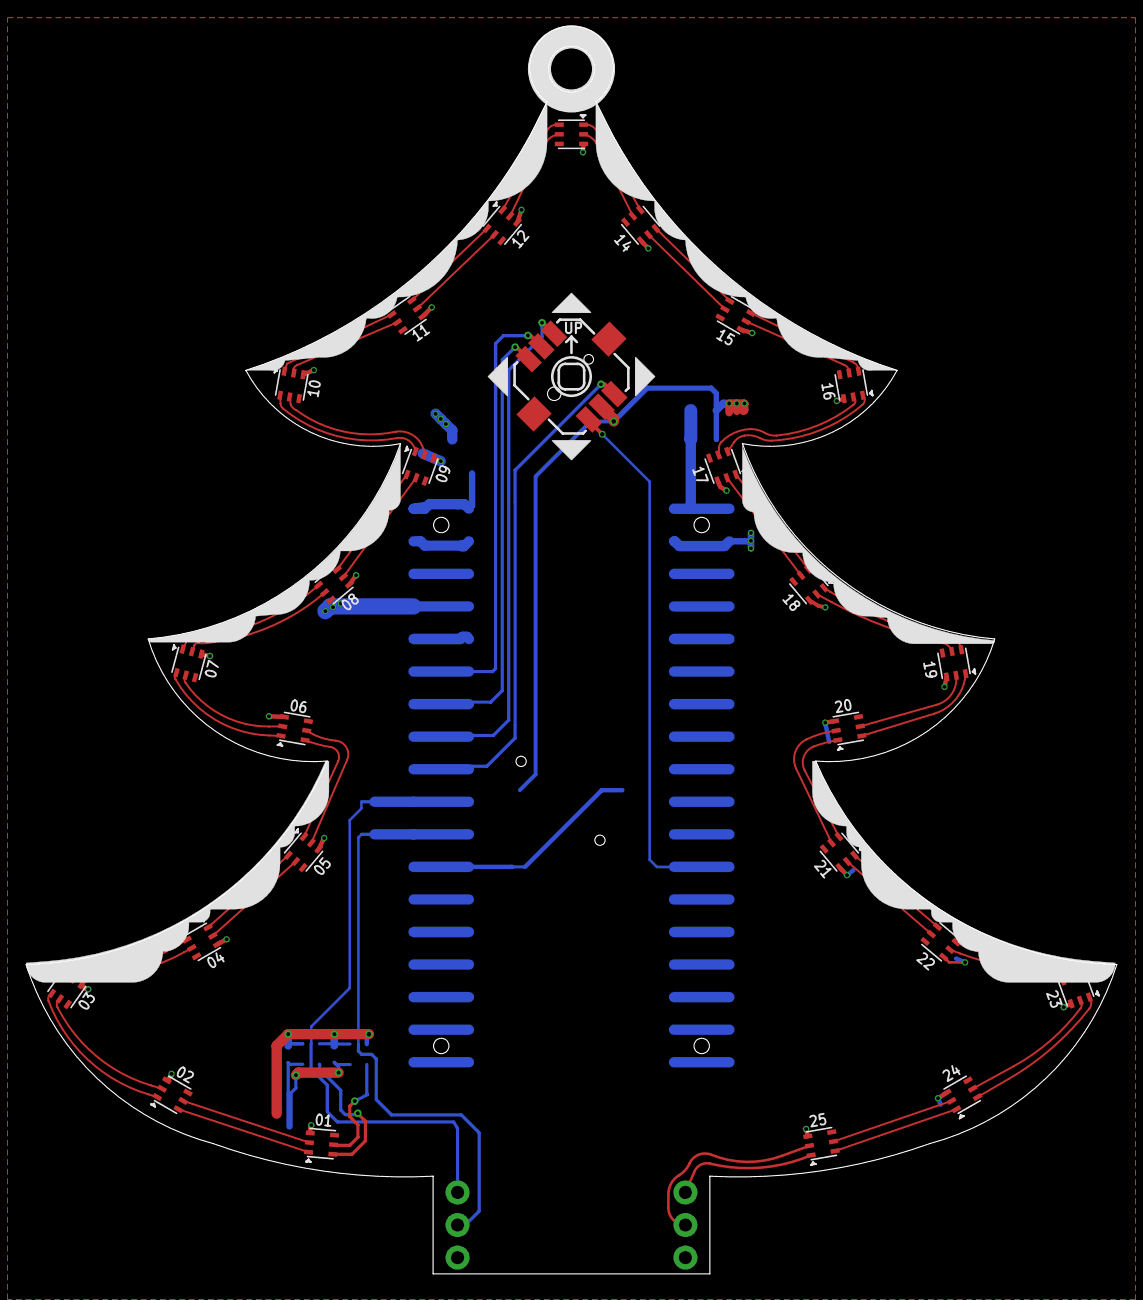
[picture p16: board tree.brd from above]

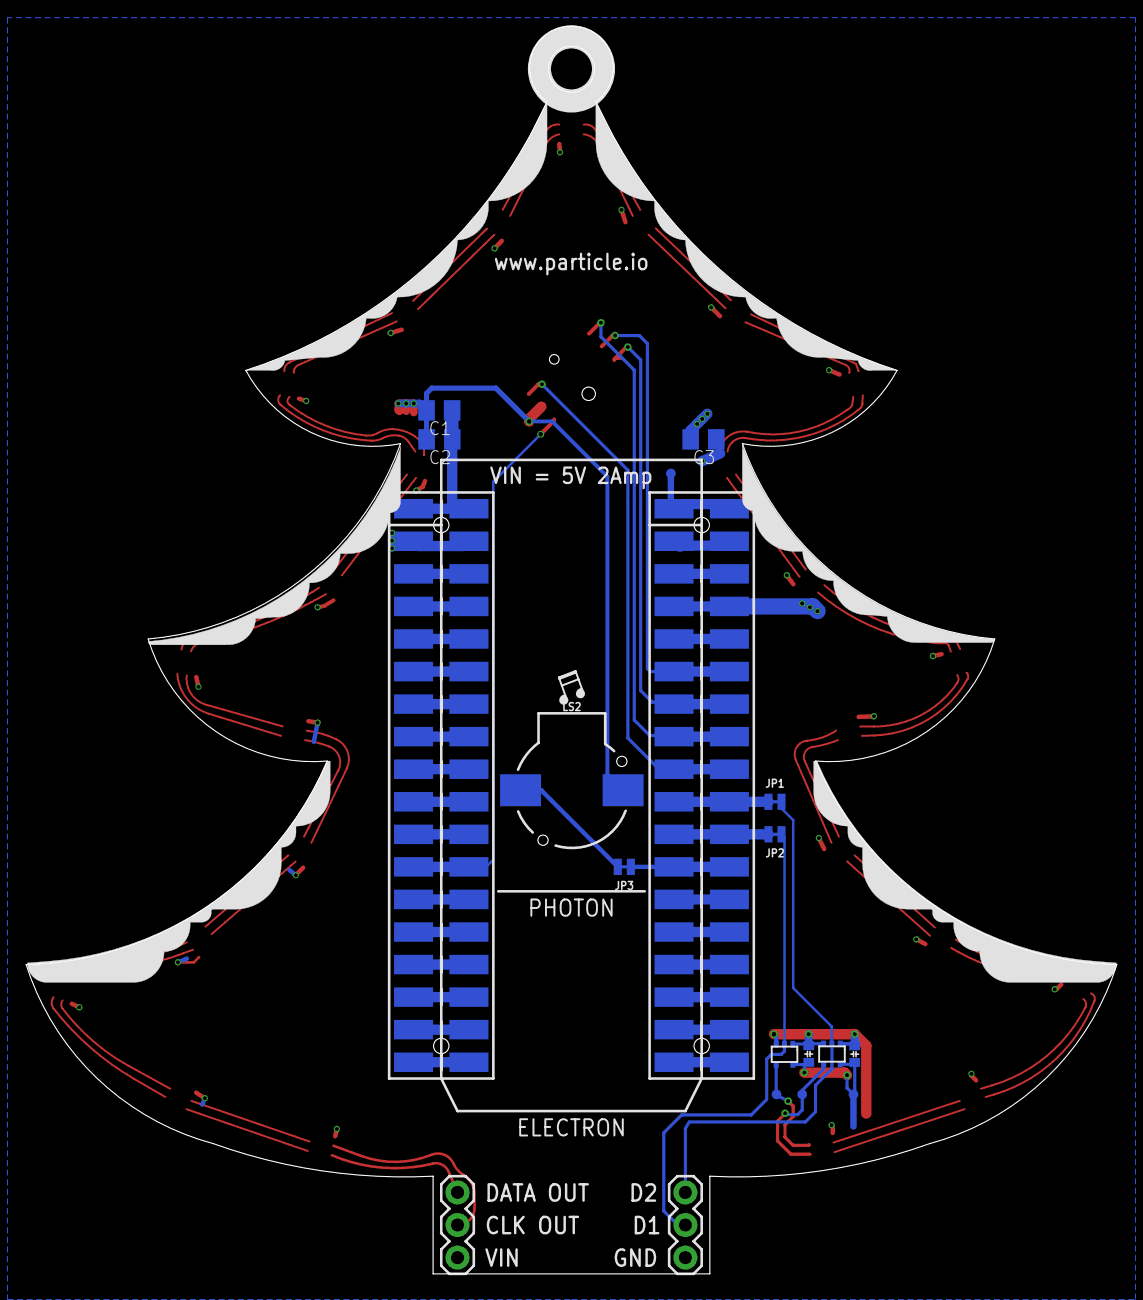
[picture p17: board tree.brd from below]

Board: 2 copper layers, 85.1 x 97.3 mm, 45 parts (18 on the bottom side), 88 nets.

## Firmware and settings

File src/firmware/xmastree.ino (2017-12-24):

/*
 *      Copyright 2017 Particle Industries, Inc.
 *
 *      Licensed under the Apache License, Version 2.0 (the "License");
 *      you may not use this file except in compliance with the License.
 *      You may obtain a copy of the License at
 *
 *          http://www.apache.org/licenses/LICENSE-2.0
 *
 *      Unless required by applicable law or agreed to in writing, software
 *      distributed under the License is distributed on an "AS IS" BASIS,
 *      WITHOUT WARRANTIES OR CONDITIONS OF ANY KIND, either express or implied.
 *      See the License for the specific language governing permissions and
 *      limitations under the License.
 *
 */

/*
 *      Project: Xmas Tree
 *
 *      Description:
 *          This is a Xmas tree with 25 LEDs, a piezo buzzer and a 5-way joystick designed for Particle Photon
 *          and Electron connected to the cloud which demostrates how to:
 *              1.  define cloud functions for controlling the tree over the Particle Cloud.
 *              2.  generate tones using the piezo buzzer
 *              3.  create beautiful effects using the LEDs
 *              4.  control the tree state using the 5-way joystick.
 *
 */

#include "xmastree.h"       // All macros (#define) are in xmastree.h
#include <dotstar.h>

/* Project name and version */
#define WHOAMI              "XmasTree"
#define VERSION             1

/* LED brightness value */
/* Warning: less than 80 is highly recommended for safety and for your eyes */
#define LED_BRIGHTNESS      30

/* Project name and version */
const char projName[] = WHOAMI;
const int version = VERSION;

/* Current song selected */
int currentSong = 0;

/* Current animation selected */
int currentAnimation = 0;

/* Current state of the effect when pressing the center button */
int currentState = STATE_NONE;

/* Set to TRUE to play the current song repeatedly */
bool repeatSong = FALSE;

/* Current button down */
volatile int buttonState = BUTTON_NONE;

/* Create an instance for the xmasTree LEDs, each LED controlled by two pins, DATA and Clock */
Adafruit_DotStar leds = Adafruit_DotStar(TOTAL_LED, PIN_LED_DATA, PIN_LED_CLOCK, DOTSTAR_BGR);

/* Two threads will be used for processing songs and LED animations */
Thread *animationWorker, *songWorker;

/* LEDs hardware initialization */
void ledsInit()
{
    leds.setBrightness(LED_BRIGHTNESS);
    leds.begin();
    leds.clear();
    stopLED();
}

/* 5-way joystick hardware initialization */
void joystickPortInit()
{
    /* Set pins to input with internal pull-up */
    pinMode(PIN_CENTER, INPUT_PULLUP);
    pinMode(PIN_UP, INPUT_PULLUP);
    pinMode(PIN_DOWN, INPUT_PULLUP);
    pinMode(PIN_LEFT, INPUT_PULLUP);
    pinMode(PIN_RIGHT, INPUT_PULLUP);
    
    /* Using interrupts for the pins */
    attachInterrupt(PIN_CENTER, buttonHandler, FALLING);
    attachInterrupt(PIN_UP, buttonHandler, FALLING);
    attachInterrupt(PIN_DOWN, buttonHandler, FALLING);
    attachInterrupt(PIN_LEFT, buttonHandler, FALLING);
    attachInterrupt(PIN_RIGHT, buttonHandler, FALLING);
}

/* Piezo buzzer hardware initialization */
void buzzerPortInit(void)
{
    pinMode(PIN_BUZZER, OUTPUT);
}

/* Set all the LEDs to color, e.g. "0xFF0000" = Red */
int playLED(String color)
{
    for (int i = 0; i < TOTAL_LED; i++)
        leds.setPixelColor(i, strtol(color, NULL, 0));
    leds.show();
}

/* Turn off all LEDs */
void stopLED()
{
    playLED("0x000000"); // R,G,B = 0,0,0
}

void playTone(int freq, int duration)
{
    Serial.println("playTone");
    tone(PIN_BUZZER, freq, duration);
}

void stopTone(String)
{
    noTone(PIN_BUZZER);
}

/* For publishing the device-connected event to the cloud */
void publishConnected()
{
    Serial.println("publishConnected");
    Particle.publish("xtreeConnected", projName);
}

/* For publishing the effect state changed event to the cloud */
void publishStateChanged()
{
    Serial.println("publishStateChanged");
    Particle.publish("stateChanged", String(currentState));
}

/* For publishing the animation changed event to the cloud */
void publishAnimationChanged()
{
    Serial.println("publishAnimationChanged");
    Particle.publish("animChanged", String(currentAnimation));
}

/* For publishing the song changed event to the cloud */
void publishSongChanged()
{
    Serial.println("publishSongChanged");
    Particle.publish("songChanged", String(currentSong));
}

#include "songs.h"
#include "animations.h"

/* The no. of songs and LED animations, defined in songs.h and animations.h */
int songCount = SONG_COUNT; 
int animationCount = ANIMATION_COUNT;

/* Play a song by the song ID */
int playSong(String songIndex)
{
    Serial.println("playSong");
    
    /* Stop the current playing song at once */
    changeSong = true;

    /* Set the current song and the song worker will play it */
    currentSong = atoi(songIndex);

    /* Update the tree current state */    
    if (currentState == STATE_NONE)
        currentState = STATE_SONG;
    else if (currentState == STATE_ANIMATION)
        currentState = STATE_BOTH;
    
    return 1;
}

/* Stop the current song playing */
int stopSong(String)
{
    Serial.println("stopSong");

    /* Stop the current playing song at once */
    changeSong = true;

    /* Update the tree current state */    
    if (currentState == STATE_SONG)
        currentState = STATE_NONE;
    else if (currentState == STATE_BOTH)
        currentState = STATE_ANIMATION;
        
    return 1;
}

/* Play a LED animation by the animation ID */
int playAnimation(String animationIndex)
{
    Serial.println("playAnimation");

    /* Stop the current playing animation at once */
    changeAnimation = true;

    /* Set the current song and the animation worker will play it */
    currentAnimation = atoi(animationIndex);

    /* Update the tree current state */    
    if (currentState == STATE_NONE)
        currentState = STATE_ANIMATION;
    else if (currentState == STATE_SONG)
        currentState = STATE_BOTH;

    return 1;
}

/* Stop the LED cureent playing animation */
int stopAnimation(String)
{
    Serial.println("stopAnimation");

    /* Stop the current playing animation at once */
    changeAnimation = true;
    stopLED();

    /* Update the tree current state */
    if (currentState == STATE_ANIMATION)
        currentState = STATE_NONE;
    else if (currentState == STATE_BOTH)
        currentState = STATE_SONG;

    return 1;
}

/* Toggle the state of the tree for the Center button */
int toggleState()
{
    currentState++;
    if (currentState > STATE_MAX)
        currentState = 0;
    
    Serial.println("toggleState");

    if (currentState == STATE_NONE || currentState == STATE_SONG)
        stopAnimation("");

    if (currentState == STATE_NONE || currentState == STATE_ANIMATION)
        stopSong("");

    return currentState;
}

/* Set the state of the tree */
int setState(String state)
{
    Serial.println("setState");

    if (String(currentState) == state)
        return 0;
        
    if ( (state == "BOTH") || (state == String(STATE_BOTH)) ) {
        playSong(String(currentSong));
        playAnimation(String(currentAnimation));
        currentState = STATE_BOTH;
    } else if ( (state == "SONG") || (state == String(STATE_SONG)) ) {
        playSong(String(currentSong));
        stopAnimation("");
        currentState = STATE_SONG;
    } else if ( (state == "ANIMATION") || (state == String(STATE_ANIMATION)) ) {
        stopSong("");
        playAnimation(String(currentAnimation));
        currentState = STATE_ANIMATION;
    } else if ( (state == "NONE") || (state == String(STATE_NONE)) ) {
        stopSong("");
        stopAnimation("");
        currentState = STATE_NONE;
    } else
        return -1;
    
    return 1;
}

/* Start playing the next song */
int nextSong()
{
    Serial.println("nextSong");

    /* if the state is not playing song, then do nothing */ 
    if ( (currentState == STATE_SONG) || (currentState == STATE_BOTH) ) {
        currentSong++;
        if (currentSong == songCount)
            currentSong = 0;
        
        changeSong = true;
    }

    return currentSong;
}

/* Start playing the previous song */
int prevSong()
{
    Serial.println("prevSong");

    if ( (currentState == STATE_SONG) || (currentState == STATE_BOTH) ) {
        currentSong--;
        if (currentSong < 0)
            currentSong = songCount-1;
                
        changeSong = true;
    }

    return currentSong;
}

/* Start playing the next animation */
int nextAnimation()
{
    Serial.println("nextAnimation");

    if ( (currentState == STATE_ANIMATION) || (currentState == STATE_BOTH) ) {
        currentAnimation++;
        if (currentAnimation == animationCount)
            currentAnimation = 0;
            
        changeAnimation = true;
    }

    return currentAnimation;
}

/* Start playing the previous LED animation */
int prevAnimation()
{
    Serial.println("prevAnimation");

    if ( (currentState == STATE_ANIMATION) || (currentState == STATE_BOTH) ) {
        currentAnimation--;
        if (currentAnimation < 0)
            currentAnimation = animationCount-1;

        changeAnimation = true;
    }
    
    return currentAnimation;
}

/* Process the button states */
int buttonPressed(String direction)
{
    Serial.print("buttonPressed: ");
    Serial.println(direction);
    
    if ( direction == "CENTER" || direction == String(BUTTON_CENTER) )
        return toggleState();
    else if ( direction == "UP" || direction == String(BUTTON_UP) )
        return prevAnimation();
    else if ( direction == "DOWN" || direction == String(BUTTON_DOWN) )
        return nextAnimation();
    else if ( direction == "LEFT" || direction == String(BUTTON_LEFT) )
        return prevSong();
    else if ( direction == "RIGHT" || direction == String(BUTTON_RIGHT) )
        return nextSong();
    else
        return -1;
}

/* Interrupt handler for the 5-way joystick */
void buttonHandler()
{
    if (digitalRead(PIN_CENTER) == LOW)
        buttonState = BUTTON_CENTER;
    else if (digitalRead(PIN_UP) == LOW)
        buttonState = BUTTON_UP;
    else if (digitalRead(PIN_DOWN) == LOW)
        buttonState = BUTTON_DOWN;
    else if (digitalRead(PIN_LEFT) == LOW)
        buttonState = BUTTON_LEFT;
    else if (digitalRead(PIN_RIGHT) == LOW)
        buttonState = BUTTON_RIGHT;
}

/* Process buttons for the 5-way joystick */
void processButtons()
{
    if (buttonState != BUTTON_NONE) {

        /* Wait until button up */        
        if ( (digitalRead(PIN_CENTER) == LOW) || (digitalRead(PIN_UP) == LOW) ||
            (digitalRead(PIN_DOWN) == LOW) || (digitalRead(PIN_LEFT) == LOW) ||
            (digitalRead(PIN_RIGHT) == LOW) )
            return;
        
        if (buttonState == BUTTON_CENTER)
            buttonPressed("CENTER");
        else if (buttonState == BUTTON_UP)
            buttonPressed("UP");
        else if (buttonState == BUTTON_DOWN)
            buttonPressed("DOWN");
        else if (buttonState == BUTTON_LEFT)
            buttonPressed("LEFT");
        else if (buttonState == BUTTON_RIGHT)
            buttonPressed("RIGHT");
        
        /* Clear the button state */
        buttonState = BUTTON_NONE;
    }
}

/* Button pressed from the cloud */ 
void buttonEventHandler(const char *event, const char *data)
{
    if (String(event) == "btnPressed")
        buttonPressed(String(data));
}

/* Process LED animations */
void processAnimations()
{
    /* This is an endless loop to process the animations one by one */
    while (1) {
        changeAnimation = false;

       if (currentState == STATE_BOTH || currentState == STATE_ANIMATION) {
            if (currentAnimation == WHITEOVERRAINBOW)
                whiteOverRainbow(20,75,5); 
            else if (currentAnimation == RAINBOWFADE2WHITE)
                rainbowFade2White(3, 6, 1);
            else if (currentAnimation == PULSEWHITE)
                pulseWhite(5);
            else if (currentAnimation == REDGREEN)
                redGreen(500);
            else if (currentAnimation == SPARKCYAN)
                sparkCyan(3);
        }

        delay(250);
    }
}

/* Process songs */
void processSongs()
{
    /* This is an endless loop to process the songs one by one */
    while (1) {
        changeSong = false;

        if ( (currentState == STATE_BOTH) || (currentState == STATE_SONG) ) {
            if (currentSong == SONG_JOYTOTHEWORLD)
                playJoyToTheWorld();
            else if (currentSong == SONG_WEWHISHYOUAMERRYXMAS)
                playWeWishYouAMerryXmas();
            else if (currentSong == SONG_RUDOLFTHEREDNOSEDREINDEER)
                playRudolfTheRedNosedReindeer();
            else if (currentSong == SONG_JINGLEBELLS)
                playJingleBells();
            else if (currentSong == SONG_SILENTNIGHT)
                playSilentNight();
        }

        delay(2000);
    }
}

/* Cloud functions, variables, events initialization */
void cloudInit()
{
    /* Cloud variables */
    Particle.variable("whoami", projName);
    Particle.variable("version", version);
    
    Particle.variable("songList", songList);
    Particle.variable("animList", animationList);

    Particle.variable("currSong", currentSong);
    Particle.variable("currAnim", currentAnimation);
    Particle.variable("currState", currentState);
    Particle.variable("songCount", songCount);
    Particle.variable("animCount", animationCount);

    /* Cloud functions */
    Particle.function("playLED", playLED);
    Particle.function("btnPressed", buttonPressed);
    Particle.function("setState", setState);
    Particle.function("playSong", playSong);
    Particle.function("playAnim", playAnimation);
    Particle.function("stopSong", stopSong);
    Particle.function("stopAnim", stopAnimation);

    /* Cloud subscription */
    Particle.subscribe("btnPressed", buttonEventHandler);
    
    /* Publish this event once connected to the cloud */
    publishConnected();
}

/* Process cloud events */
void processCloud()
{
    static int savedSong = -1;
    static int savedAnimation = -1;
    static int savedState = -1;

    if (savedSong != currentSong) {
        savedSong = currentSong;
        publishSongChanged();
    }
    
    if (savedAnimation != currentAnimation) {
        savedAnimation = currentAnimation;
        publishAnimationChanged();
    }

    if (savedState != currentState) {
        savedState = currentState;
        publishStateChanged();
    }
}

/* Print out the tree state to serial port */
void printTree()
{
    static int savedSong = -1;
    static int savedAnimation = -1;
    static int savedState = -1;
    
    if (savedState != currentState) {
        Serial.print("Current State: ");
        Serial.println(currentState);
        savedState = currentState;
    }

    if (savedSong != currentSong) {
        Serial.print("Current Song: ");
        Serial.println(currentSong);
        savedSong = currentSong;
    }

    if (savedAnimation != currentAnimation) {
        Serial.print("Current Animation: ");
        Serial.println(currentAnimation);
        savedAnimation = currentAnimation;
    }
}

/* Wiring programming starts from setup() and then calling loop() */
void setup()
{
    /* LEDs setup */
    ledsInit();
    
    /* 5-way joystick setup */
    joystickPortInit();

    /* Buzzer setup */
    buzzerPortInit();

    /* Cloud functions and variables setup */
    cloudInit();
    
    /* Creating a thread for processing LED animations and songs */
    /* So that I can just need to keep track of the buttons and the cloud activities */
    animationWorker = new Thread("animation", processAnimations);
    songWorker = new Thread("song", processSongs);
    
    /* Start to play the 1st song and LED animation */
    playSong("0");
    playAnimation("0");
}

/* This will be called repeatedly */
void loop()
{
    /* Print the tree info. */
    printTree();
    
    /* Check if button pressed */
    processButtons();
    
    /* Process the Cloud events */
    processCloud();
}

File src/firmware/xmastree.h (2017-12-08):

/* Buzzer pin */
#define PIN_BUZZER          D0

/* LEDs control pins */
#define PIN_LED_CLOCK       D1
#define PIN_LED_DATA        D2

/* 5-way button pins */
#define PIN_CENTER          D6
#define PIN_UP              D4
#define PIN_DOWN            A0
#define PIN_LEFT            D5
#define PIN_RIGHT           D3

/* LED count */
#define TOTAL_LED           25

/* Button IDs */
#define BUTTON_NONE         -1
#define BUTTON_CENTER       0
#define BUTTON_UP           1
#define BUTTON_DOWN         2
#define BUTTON_LEFT         3
#define BUTTON_RIGHT        4

/* Toggle state */
#define STATE_NONE          0   // Stop LED animation and song
#define STATE_ANIMATION     1   // Playing animation only
#define STATE_SONG          2   // Playing song only
#define STATE_BOTH          3   // Playing song and animation
#define STATE_MAX           3

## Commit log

2017-12-08 🎄🎄🎄❄️⛄️🤶 v1 🎅⛄️❄️🎄🎄🎄
    [tree.brd, tree.sch]
2017-12-10 D4 🎵
2017-12-15 Change LED color ordering and add red on green animation
    Fixes #1
    [xmastree.ino]
2017-12-18 A correct practice for adding songs, also some minor fixes.
    [xmastree.ino]

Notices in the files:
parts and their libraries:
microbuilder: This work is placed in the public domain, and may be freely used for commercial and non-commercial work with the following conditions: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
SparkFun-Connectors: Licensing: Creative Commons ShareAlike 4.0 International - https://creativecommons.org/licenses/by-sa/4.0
